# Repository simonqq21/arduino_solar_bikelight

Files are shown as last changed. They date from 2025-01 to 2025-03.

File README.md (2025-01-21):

# Arduino Solar Rear Bicycle Light 
## Main Hardware Components
- Arduino Nano
- 6V 1W solar panel 
- TP4056 li-ion charger with BMS chip 
- 18650 battery holder with 18650 battery x1  
- 10k resistor (charging input voltage divider)
- 50k resistor (charging input voltage divider) 
- 10k resistor (battery voltage divider)
- 50k resistor (battery panel voltage divider) 
- Diffused red LED x5 (dim light, one as a charging indicator when turned off)
- 150R resistor x5
- Clear red LED x4 (bright light) 
- 150R resistor x4
- 2N3904 NPN transistor x2
- 10k resistor x2
- Momentary pushbutton 

## Things to calculate/ measure: 
solar panel no-load voltage 
solar panel max current
expected battery charge time 
expected runtime 
voltage divider resistances 

assume 6V max voltage input, 5V max voltage output 
6 * r2 / (r1 + r2) = 5 
6 * r2 = 5 * (r1 + r2)
6 * r2 = 5 * r1 + 5 * r2 
r2 = 5 * r1 
The current through the voltage divider must be minimal. 
if r2 is 50k, r1 is 10k.

LED current limiting resistors 
diffused LED 

Li-ion voltage max 4.2V 
LED current = 20mA
(4.2-2.1)/0.02 = 105 R resistor minimum

clear LED

Li-ion voltage max 4.2V 
LED current = 30mA
(4.2-2.1)/0.03 = 70 R resistor minimum

Calculations for the voltage divider resistances when using the internal 1.1V Vref 

Min input (PV panel and USB charger) voltage: 0V
Max input (PV panel and USB charger) voltage: 7V
max USB charger voltage: 5V
max PV panel voltage: ~7V - 0.3V = 6.7V (0.3V voltage drop from the diode)
Max input (PV panel and USB charger) voltage: 6.7 ~= 7V
Vin = 7V 
Vout = 1.1V
7* r2/(r1+r2) = 1.1
7r2 = 1.1r1 + 1.1r2 
5.9r2 = 1.1r1 
r1 = 5.9r2/1.1
r2 = 10k 
r1 = 53636.364 ~= 53k 

Min battery voltage: 3.0V
Max battery voltage: 4.2V
Vin = 4.2V
Vout = 1.1V
4.2* r2/(r1+r2) = 1.1 
4.2r2 = 1.1r1 + 1.1r2 
3.1r2 = 1.1r1
r1 = 3.1r2 / 1.1 
r2 = 10k  
r1 = 28181.818 ~= 28k 

Battery voltage divider 
r1 = 50k 
r2 = 10k 
input voltage min: 3.0V
input voltage max: 4.2V
conversion factor = 10k/(50k+10k) = 1/6 
3.0V*1/6 = 0.5V 
4.2V*1/6 = 0.7V
0.5/1.1*1023=465 
0.7/1.1*1023=651

Charging input voltage divider 
r1 = 50k 
r2 = 10k 
input voltage min: 0.0V
input voltage max: 7.0V
input voltage threshold: 4.8V 
conversion factor = 10k/(50k+10k) = 1/6 
0.0V*1/6 = 0V 
7.0V*1/6 = 1.167V
4.8V*1/6 = 0.8V  
1.167/1.1*1023=1023 (capped at 1023, but it doesn't matter anyways)
0.8/1.1*1023=744

# Power Consumption 
power consumption in Off Mode (quiescent current) 35uA
power consumption in Low Mode 78mA
power consumption in High Mode 118mA

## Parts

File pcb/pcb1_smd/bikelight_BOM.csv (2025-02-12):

Designator | Comment | Footprint | LCSC
R6,R7,R8,R9,R10,R11,R12,R13 | 150 | Resistor_SMD:R_0805_2012Metric_Pad1.20x1.40mm_HandSolder | C17471
R2,R3,R4,R5 | 10k | Resistor_SMD:R_0805_2012Metric_Pad1.20x1.40mm_HandSolder | C17414
R1 | 50k | Resistor_SMD:R_0805_2012Metric_Pad1.20x1.40mm_HandSolder | C17737
A1 | Arduino_Nano_v3.x | Module:Arduino_Nano
Q1,Q2,Q3 | BSS138 | Package_TO_SOT_SMD:SOT-23 | C78284
J1 | Conn_01x02 | Connector_JST:JST_XH_B2B-XH-AM_1x02_P2.50mm_Vertical
J2 | Conn_01x05_Pin | Connector_PinHeader_2.54mm:PinHeader_1x05_P2.54mm_Vertical
D1,D2,D3,D4,D5,D6,D7,D8 | LED | LED_THT:LED_D5.0mm
SW1 | SW_Push | Button_Switch_THT:SW_SPST_Omron_B3F-40xx

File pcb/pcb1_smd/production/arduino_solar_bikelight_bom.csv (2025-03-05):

Reference | Value | Footprint | LCSC
R6,R7,R8,R9,R10,R11,R12,R13 | 150 | Resistor_SMD:R_0805_2012Metric_Pad1.20x1.40mm_HandSolder | C17471
R2,R3,R4,R5,R15 | 10k | Resistor_SMD:R_0805_2012Metric_Pad1.20x1.40mm_HandSolder | C17414
R1 | 50k | Resistor_SMD:R_0805_2012Metric_Pad1.20x1.40mm_HandSolder | C17737
A1 | Arduino_Nano_v3.x | Module:Arduino_Nano
Q1,Q2,Q3 | BSS138 | Package_TO_SOT_SMD:SOT-23 | C78284
J1 | Conn_01x02 | Connector_JST:JST_XH_B2B-XH-AM_1x02_P2.50mm_Vertical
J2 | Conn_01x05_Pin | Connector_PinHeader_2.54mm:PinHeader_1x05_P2.54mm_Vertical
R14 | LDR07 | OptoDevice:R_LDR_5.1x4.3mm_P3.4mm_Vertical
D1,D2,D3,D4,D5,D6,D7,D8 | LED | LED_THT:LED_D5.0mm
SW1 | SW_Push | Button_Switch_THT:SW_SPST_Omron_B3F-40xx

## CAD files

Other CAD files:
battery_box v22.f3d

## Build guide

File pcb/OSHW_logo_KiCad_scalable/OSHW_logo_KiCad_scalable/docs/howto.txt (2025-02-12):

How to make your own:
---------------------

Watch / read this first:

* http://www.kicad-pcb.org/display/KICAD/Videos+by+zupnikal

The last two videos should be helpful for how to create a custom .emp file from images.

* http://www.re-innovation.co.uk/web12/index.php/en/blog-75/230-adding-logo-to-kicad

If you use linux (which you should), you don't have to use the online-scaler. Just use the scripts!

---

* Create a folder to hold your new footprint library.
* Copy the scripts 'make_lib.sh' and 'scale.pl' into that folder.
* Make sure these files are executable (chmod u+x ...).
* Copy your custom .emp file into that foler.

* Run the 'make_lib.sh' script as follows:

./make_lib.sh input-file.emp lib-name.mod START END

START and END are placeholders for positive integer numbers (1,2,3...) that determine
the range of created footprint sizes. The units are metric (mm).

The 'lib-name.mod' file will show up in the 'lib' sub-folder. Add it to your pcbnew
library settings as usual.

Footprints that are created for back-layers are automagically mirrored horizontally.
To place them onto a back-layer, hover the mouse-pointer over them and press 'f' for 'flip'.

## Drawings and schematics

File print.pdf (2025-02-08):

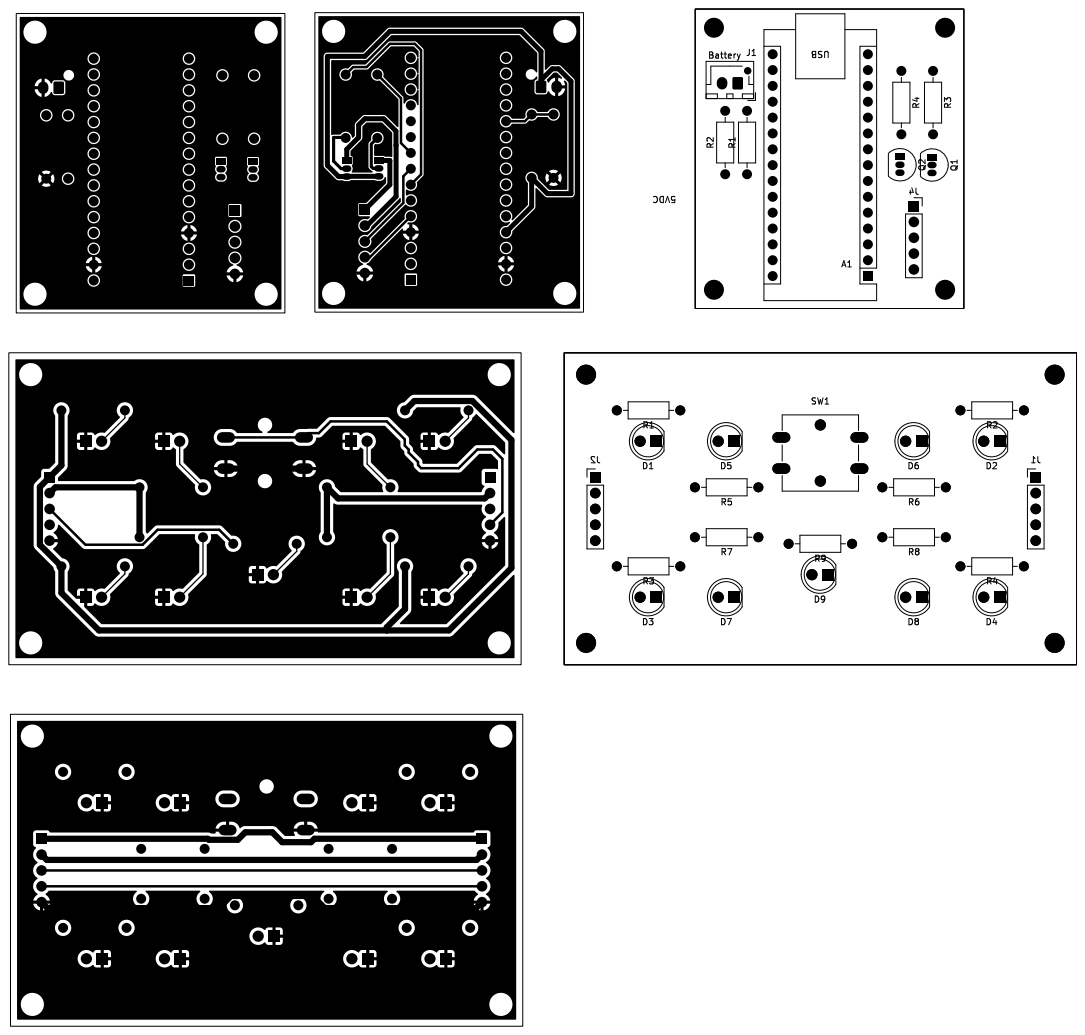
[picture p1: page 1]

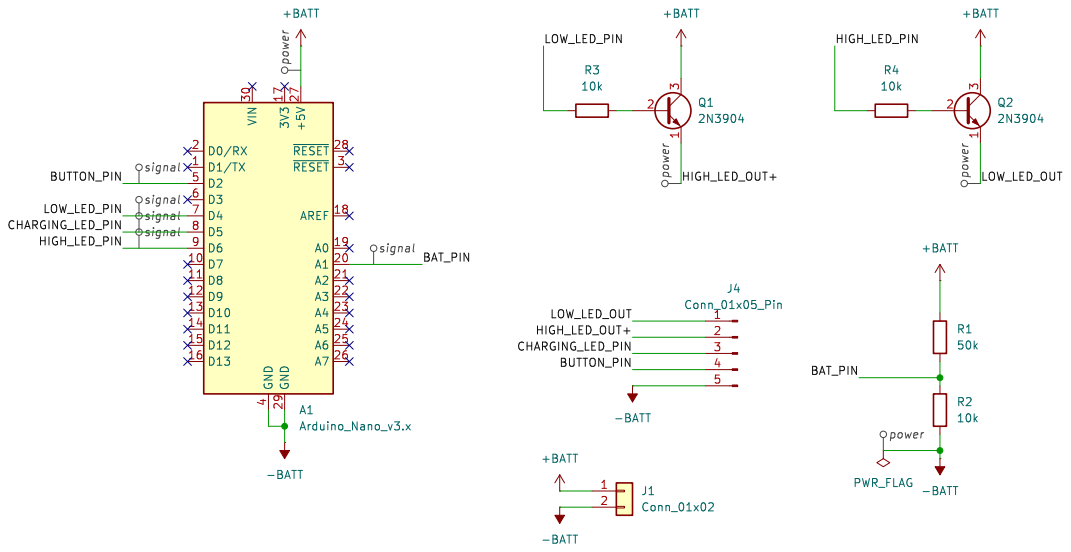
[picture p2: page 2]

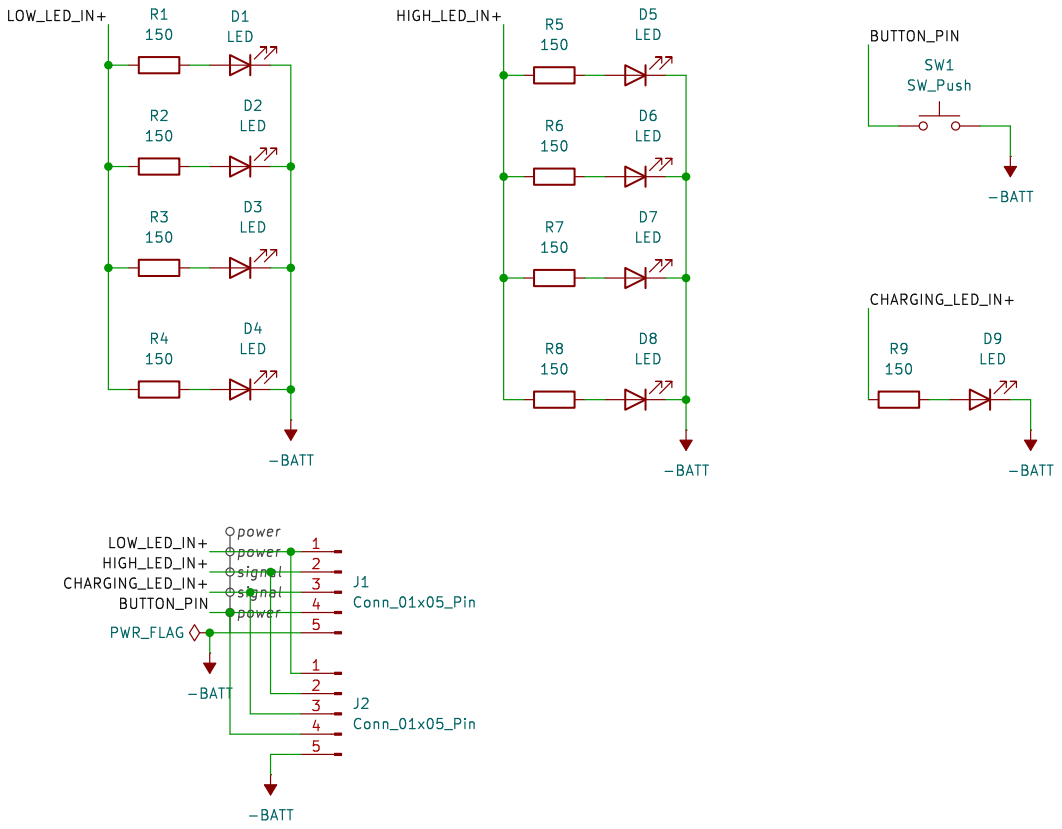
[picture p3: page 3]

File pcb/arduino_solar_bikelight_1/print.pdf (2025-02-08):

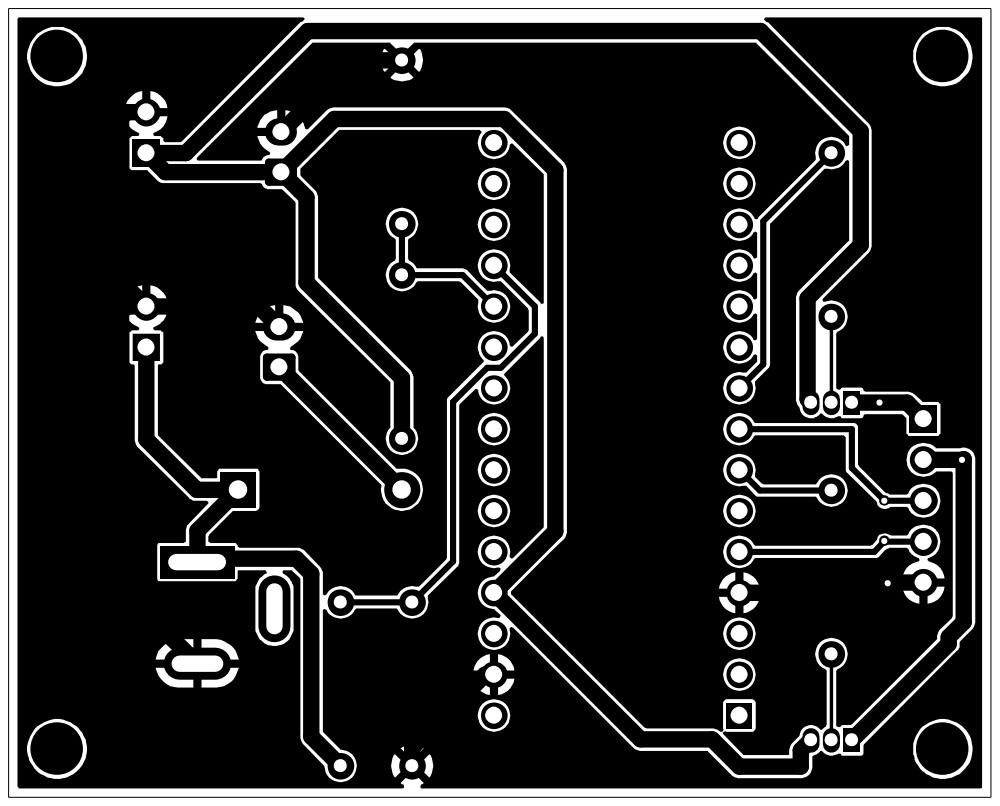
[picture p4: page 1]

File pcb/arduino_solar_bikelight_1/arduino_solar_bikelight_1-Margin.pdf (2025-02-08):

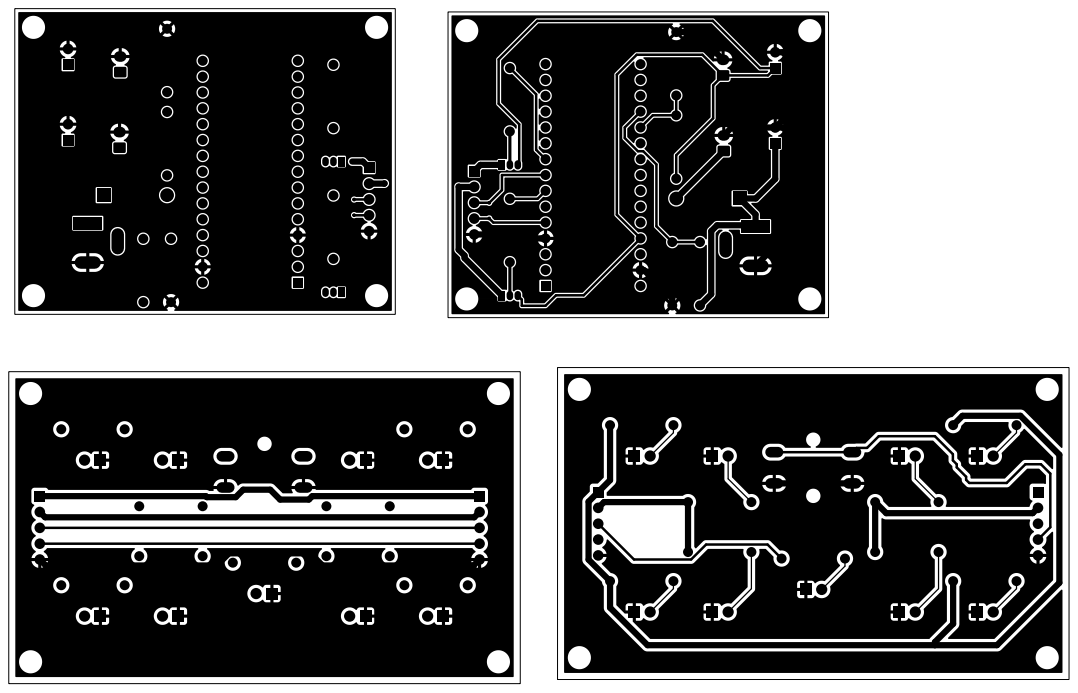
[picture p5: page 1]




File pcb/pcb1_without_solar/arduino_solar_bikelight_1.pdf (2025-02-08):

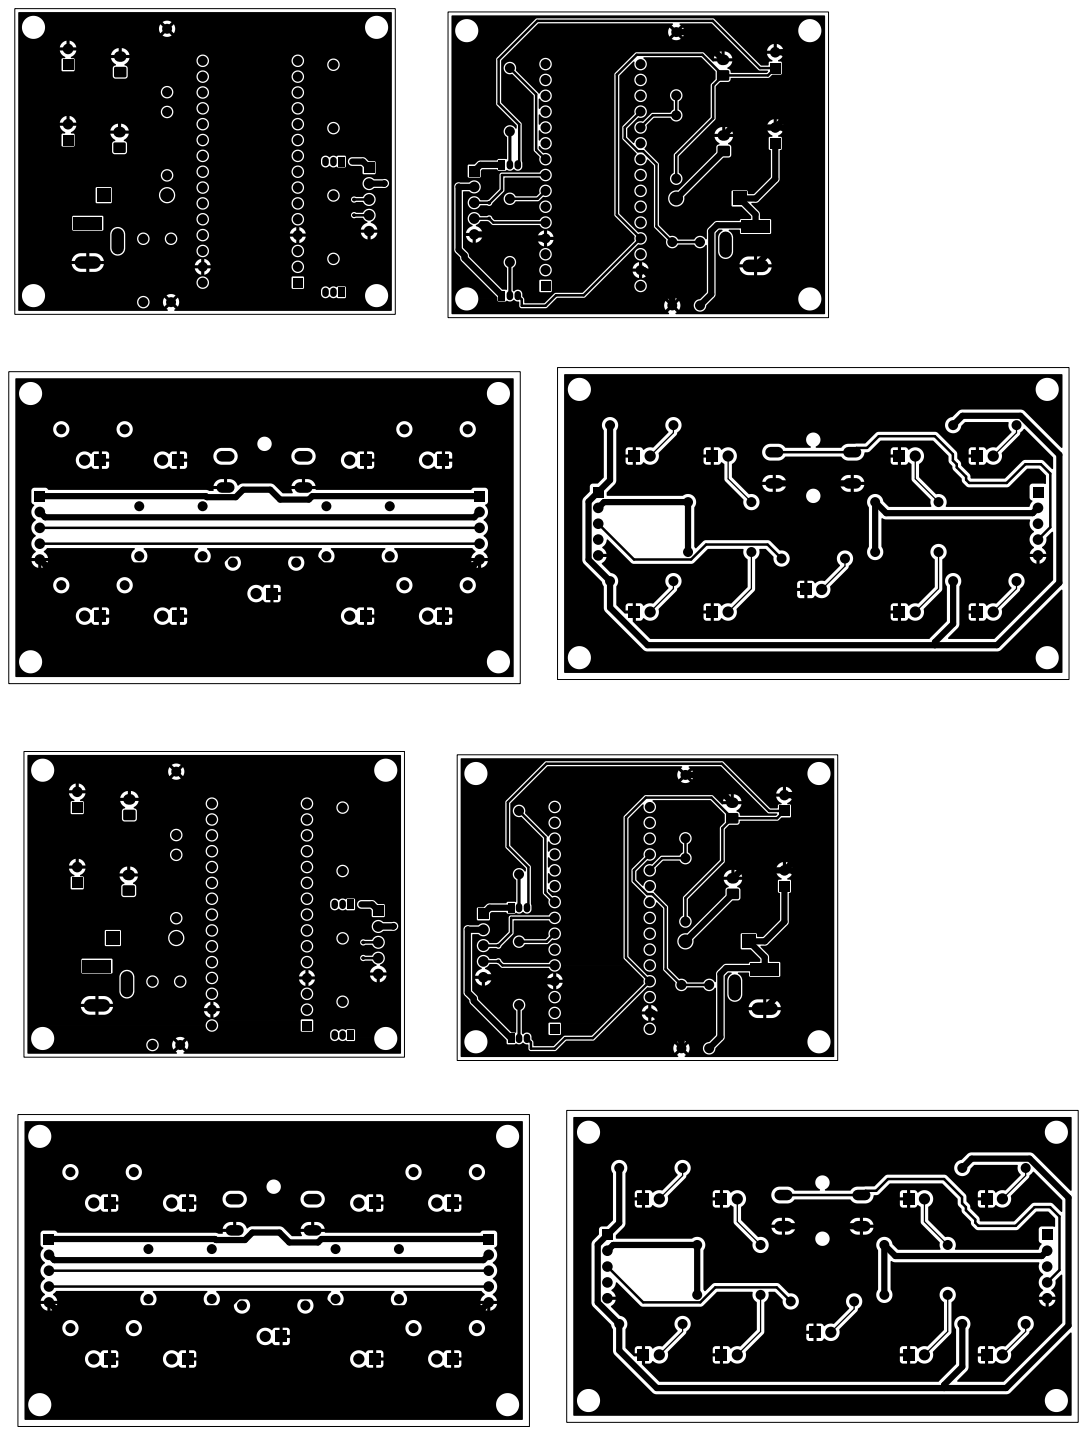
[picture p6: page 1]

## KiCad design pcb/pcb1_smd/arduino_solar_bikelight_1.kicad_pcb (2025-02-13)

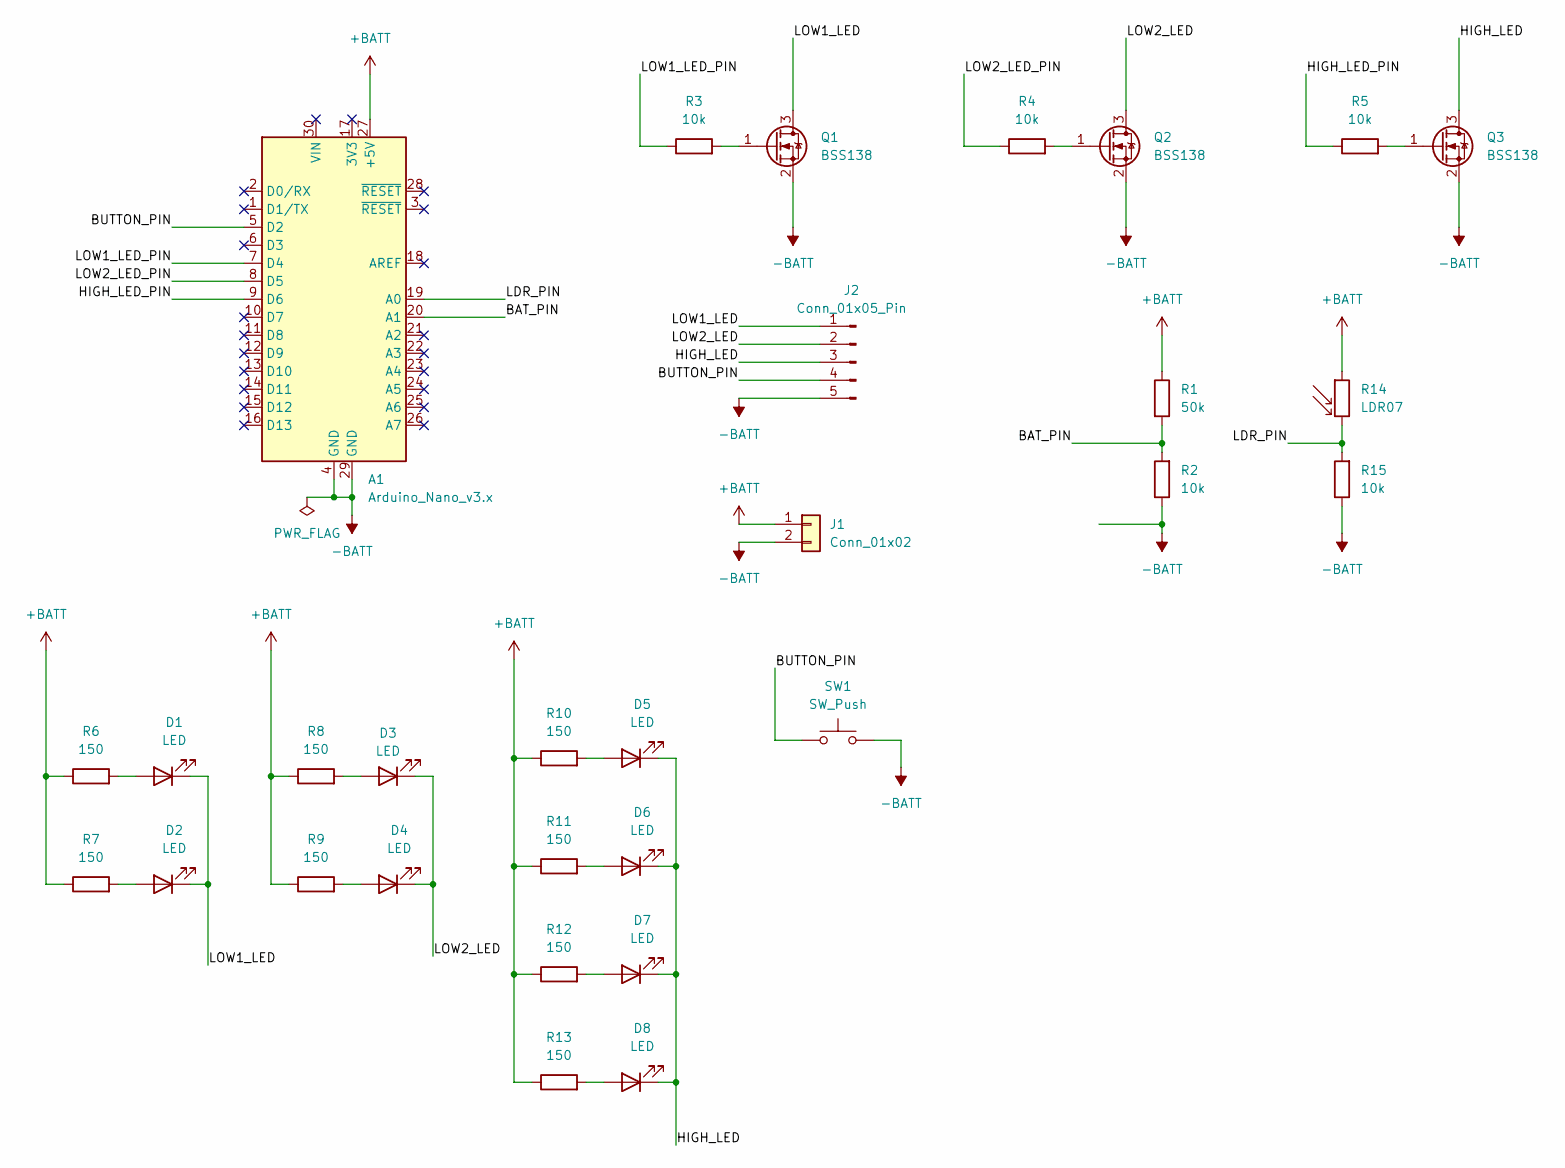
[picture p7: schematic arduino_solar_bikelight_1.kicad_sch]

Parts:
A1: Arduino_Nano_v3.x; Arduino_Nano
D1, D2, D3, D4, D5, D6, D7, D8: LED; LED_D5.0mm
J1: Conn_01x02; JST_XH_B2B-XH-AM_1x02_P2.50mm_Vertical
J2: Conn_01x05_Pin; PinHeader_1x05_P2.54mm_Vertical
Q1, Q2, Q3: BSS138; SOT-23; LCSC C78284
R1: 50k; R_0805_2012Metric_Pad1.20x1.40mm_HandSolder; LCSC C17737
R2, R3, R4, R5, R15: 10k; R_0805_2012Metric_Pad1.20x1.40mm_HandSolder; LCSC C17414
R6, R7, R8, R9, R10, R11, R12, R13: 150; R_0805_2012Metric_Pad1.20x1.40mm_HandSolder; LCSC C17471
R14: LDR07; R_LDR_5.1x4.3mm_P3.4mm_Vertical
SW1: SW_Push; SW_SPST_Omron_B3F-40xx

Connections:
+BATT: A1.27 (+5V), J1.1, R1.1, R6.1, R7.1, R8.1, R9.1, R10.1, R11.1, R12.1, R13.1, R14.1
-BATT: A1.4 (GND), A1.29 (GND), J1.2, J2.5, Q1.2 (S), Q2.2 (S), Q3.2 (S), R2.1, R15.1, SW1.2
/BAT_PIN: A1.20 (A1), R1.2, R2.2
/BUTTON_PIN: A1.5 (D2), J2.4, SW1.1
/HIGH_LED: D5.1 (K), D6.1 (K), D7.1 (K), D8.1 (K), J2.3, Q3.3 (D)
/HIGH_LED_PIN: A1.9 (D6), R5.1
/LDR_PIN: A1.19 (A0), R14.2, R15.2
/LOW1_LED: D1.1 (K), D2.1 (K), J2.1, Q1.3 (D)
/LOW1_LED_PIN: A1.7 (D4), R3.1
/LOW2_LED: D3.1 (K), D4.1 (K), J2.2, Q2.3 (D)
/LOW2_LED_PIN: A1.8 (D5), R4.1
unnamed: D1.2 (A), R6.2
unnamed: D2.2 (A), R7.2
unnamed: D3.2 (A), R8.2
unnamed: D4.2 (A), R9.2
unnamed: D5.2 (A), R10.2
unnamed: D6.2 (A), R11.2
unnamed: D7.2 (A), R12.2
unnamed: D8.2 (A), R13.2
unnamed: Q1.1 (G), R3.2
unnamed: Q2.1 (G), R4.2
unnamed: Q3.1 (G), R5.2

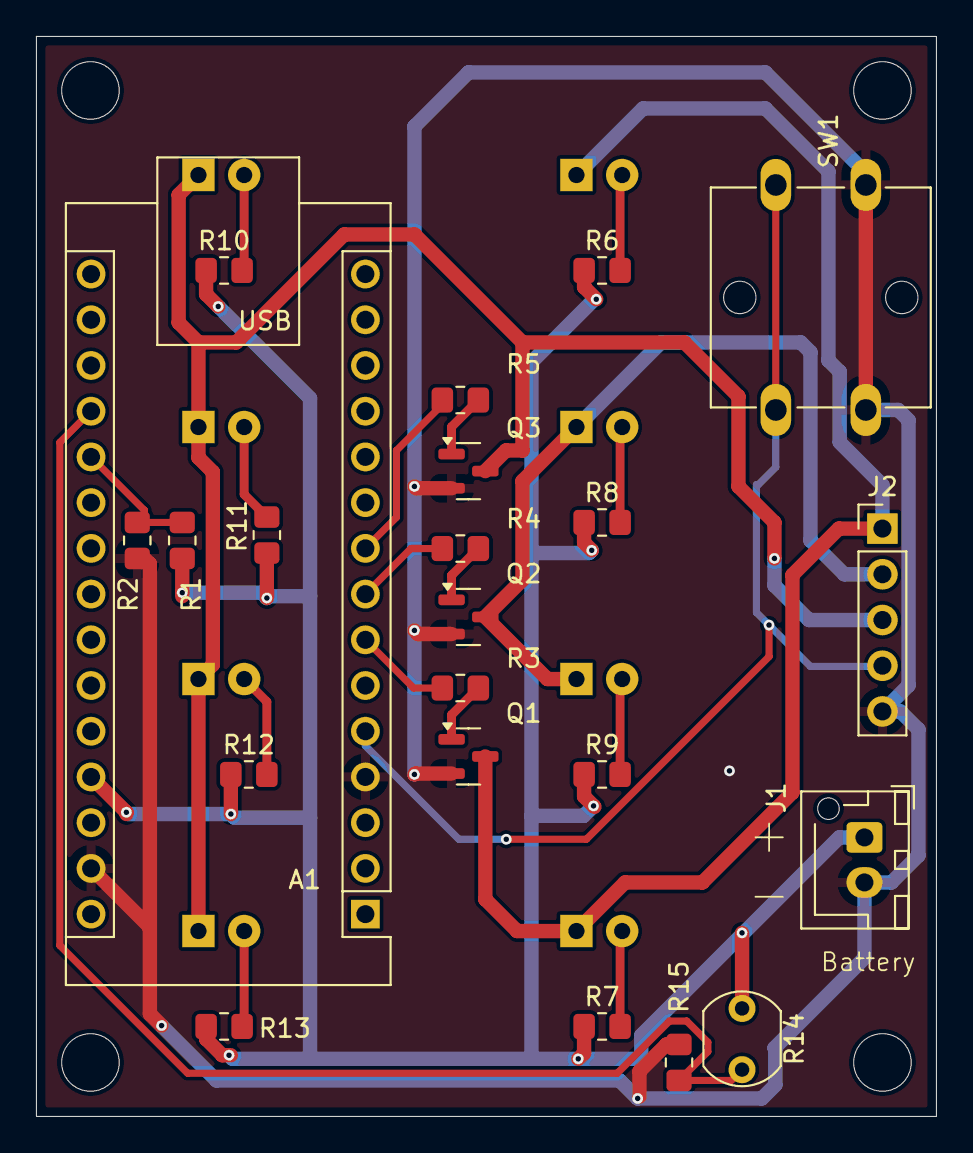
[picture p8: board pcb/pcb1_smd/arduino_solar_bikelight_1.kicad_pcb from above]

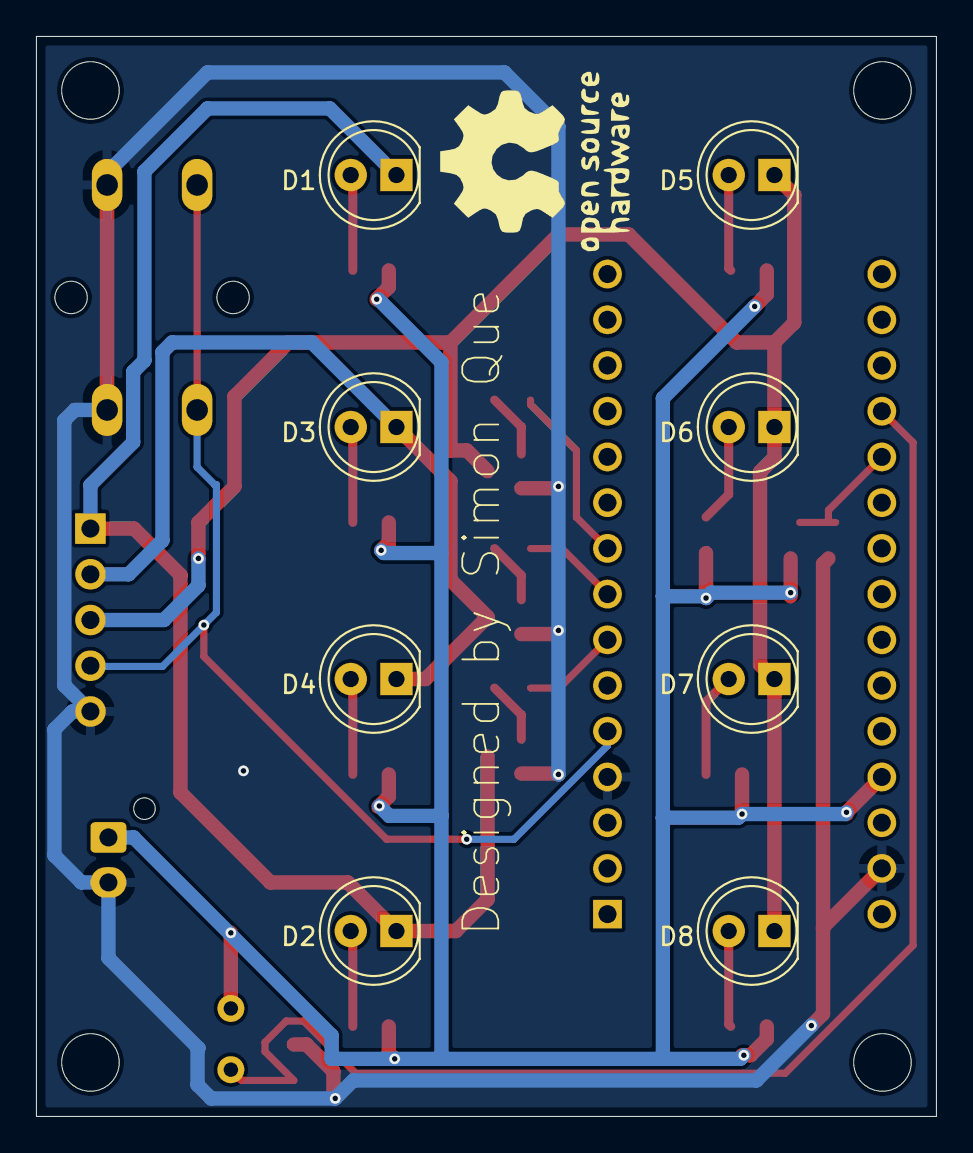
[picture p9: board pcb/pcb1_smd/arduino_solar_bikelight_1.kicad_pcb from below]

Board: 2 copper layers, 50.0 x 60.0 mm, 30 parts (8 on the bottom side), 22 nets.

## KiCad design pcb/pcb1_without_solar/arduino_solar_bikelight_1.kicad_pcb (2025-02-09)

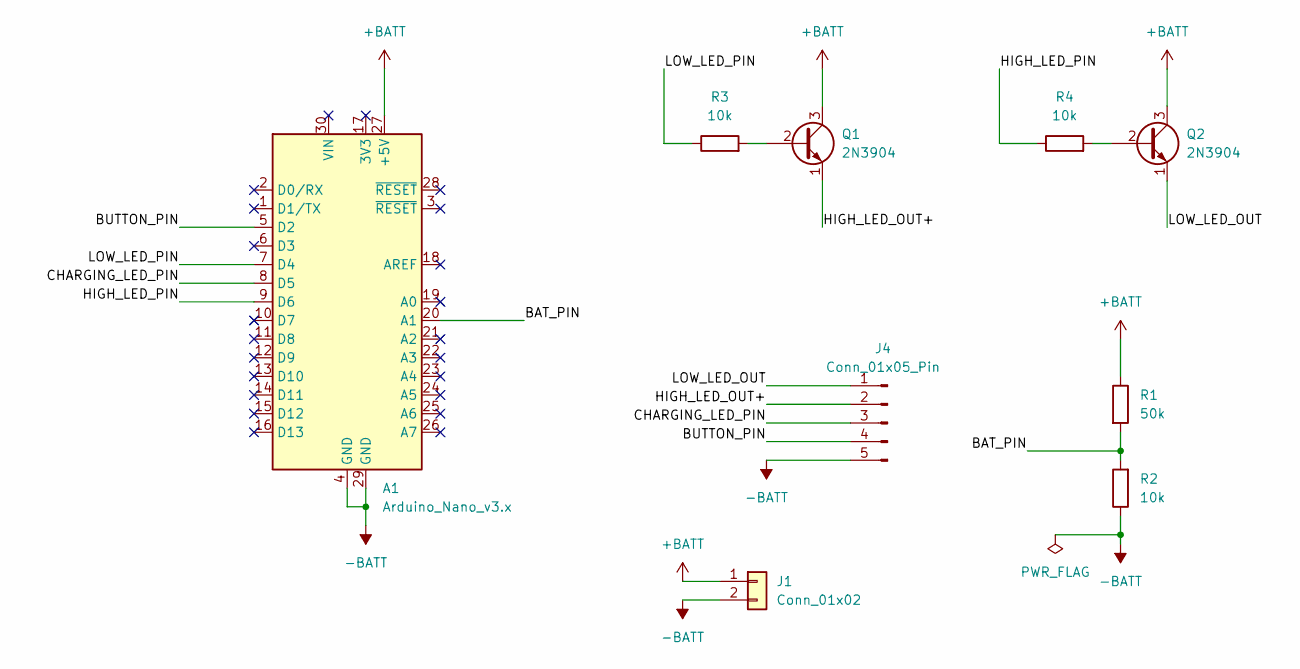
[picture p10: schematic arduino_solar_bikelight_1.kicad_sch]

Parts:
A1: Arduino_Nano_v3.x; Arduino_Nano
J1: Conn_01x02; JST_XH_B2B-XH-AM_1x02_P2.50mm_Vertical
J4: Conn_01x05_Pin; PinHeader_1x05_P2.54mm_Vertical
Q1, Q2: 2N3904; TO-92_Inline
R1: 50k; R_Axial_DIN0207_L6.3mm_D2.5mm_P10.16mm_Horizontal
R2, R3, R4: 10k; R_Axial_DIN0207_L6.3mm_D2.5mm_P10.16mm_Horizontal

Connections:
+BATT: A1.27 (+5V), J1.1, Q1.3 (C), Q2.3 (C), R1.1
-BATT: A1.4 (GND), A1.29 (GND), J1.2, J4.5, R2.1
/BAT_PIN: A1.20 (A1), R1.2, R2.2
/BUTTON_PIN: A1.5 (D2), J4.4
/CHARGING_LED_PIN: A1.8 (D5), J4.3
/HIGH_LED_OUT+: J4.2, Q1.1 (E)
/HIGH_LED_PIN: A1.9 (D6), R4.1
/LOW_LED_OUT: J4.1, Q2.1 (E)
/LOW_LED_PIN: A1.7 (D4), R3.1
unnamed: Q1.2 (B), R3.2
unnamed: Q2.2 (B), R4.2

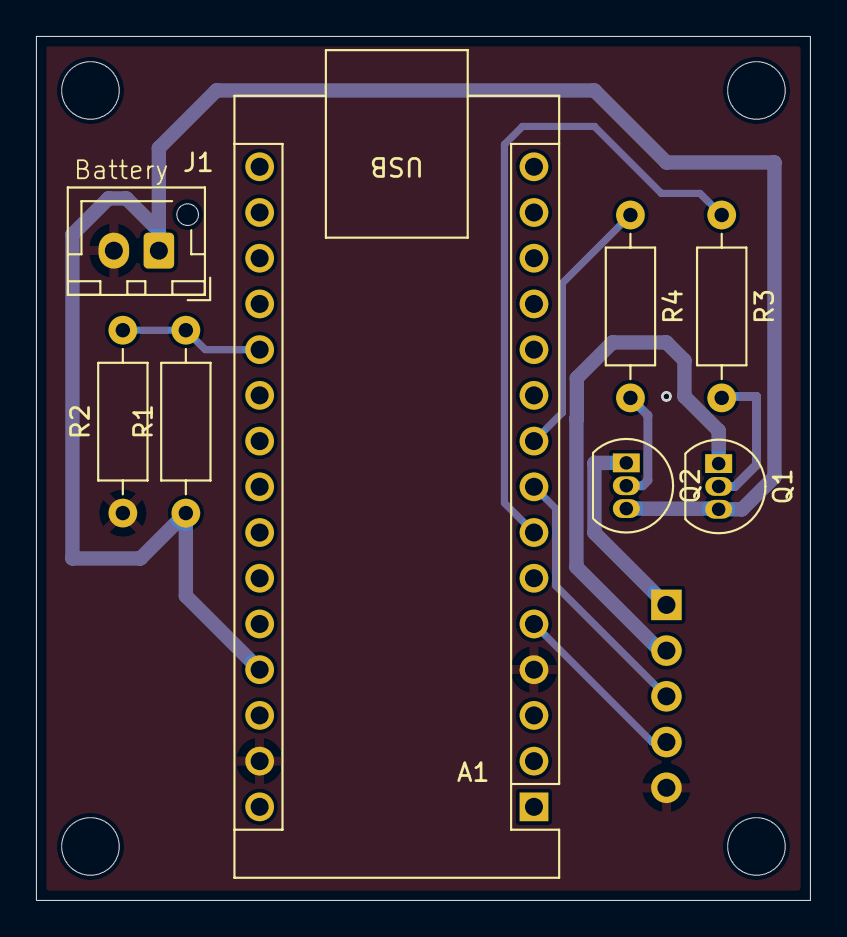
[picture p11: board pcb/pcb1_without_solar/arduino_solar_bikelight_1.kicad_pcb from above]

Board: 2 copper layers, 43.0 x 48.0 mm, 9 parts (1 on the bottom side), 11 nets.

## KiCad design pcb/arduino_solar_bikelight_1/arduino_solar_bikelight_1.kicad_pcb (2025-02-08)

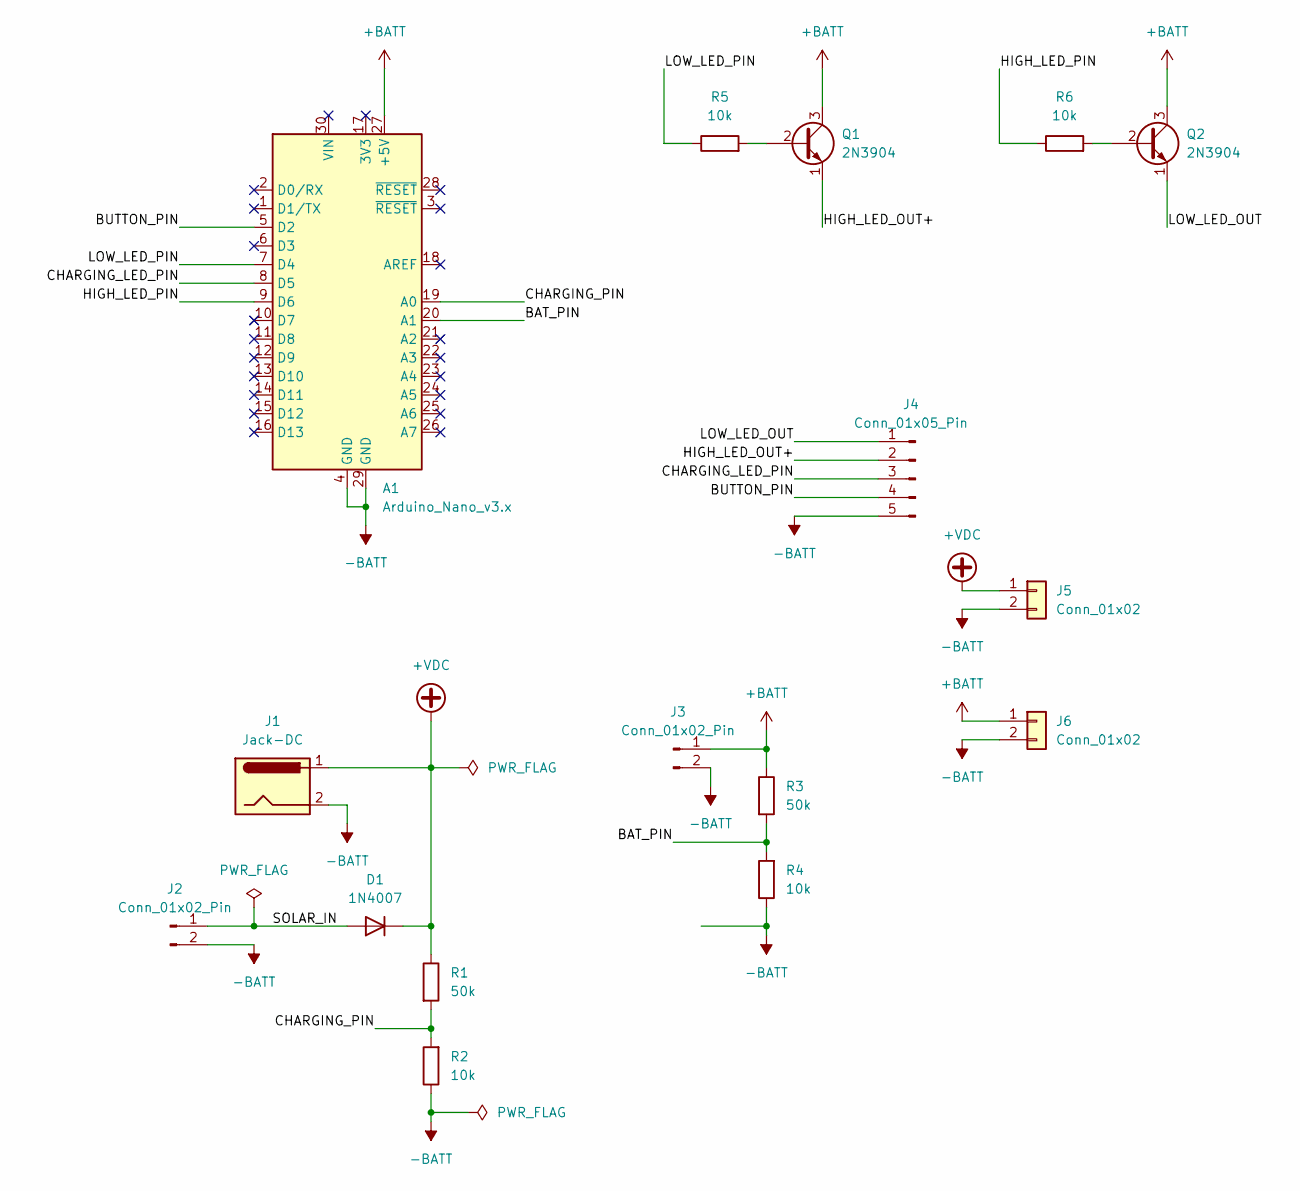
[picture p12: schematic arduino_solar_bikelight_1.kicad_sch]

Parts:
A1: Arduino_Nano_v3.x; Arduino_Nano
D1: 1N4007; D_DO-41_SOD81_P10.16mm_Horizontal
J1: Jack-DC; BarrelJack_GCT_DCJ200-10-A_Horizontal
J2, J3: Conn_01x02_Pin; JST_XH_B2B-XH-A_1x02_P2.50mm_Vertical
J4: Conn_01x05_Pin; PinHeader_1x05_P2.54mm_Vertical
J5, J6: Conn_01x02; PinHeader_2x01_P2.54mm_Vertical
Q1, Q2: 2N3904; TO-92_Inline
R1, R3: 50k; R_Axial_DIN0207_L6.3mm_D2.5mm_P10.16mm_Horizontal
R2, R4, R5, R6: 10k; R_Axial_DIN0207_L6.3mm_D2.5mm_P10.16mm_Horizontal

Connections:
+BATT: A1.27 (+5V), J3.1, J6.1, Q1.3 (C), Q2.3 (C), R3.1
+VDC: D1.1 (K), J1.1, J5.1, R1.1
-BATT: A1.4 (GND), A1.29 (GND), J1.2, J2.2, J3.2, J4.5, J5.2, J6.2, R2.1, R4.1
/BAT_PIN: A1.20 (A1), R3.2, R4.2
/BUTTON_PIN: A1.5 (D2), J4.4
/CHARGING_LED_PIN: A1.8 (D5), J4.3
/CHARGING_PIN: A1.19 (A0), R1.2, R2.2
/HIGH_LED_OUT+: J4.2, Q1.1 (E)
/HIGH_LED_PIN: A1.9 (D6), R6.1
/LOW_LED_OUT: J4.1, Q2.1 (E)
/LOW_LED_PIN: A1.7 (D4), R5.1
/SOLAR_IN: D1.2 (A), J2.1
unnamed: Q1.2 (B), R5.2
unnamed: Q2.2 (B), R6.2

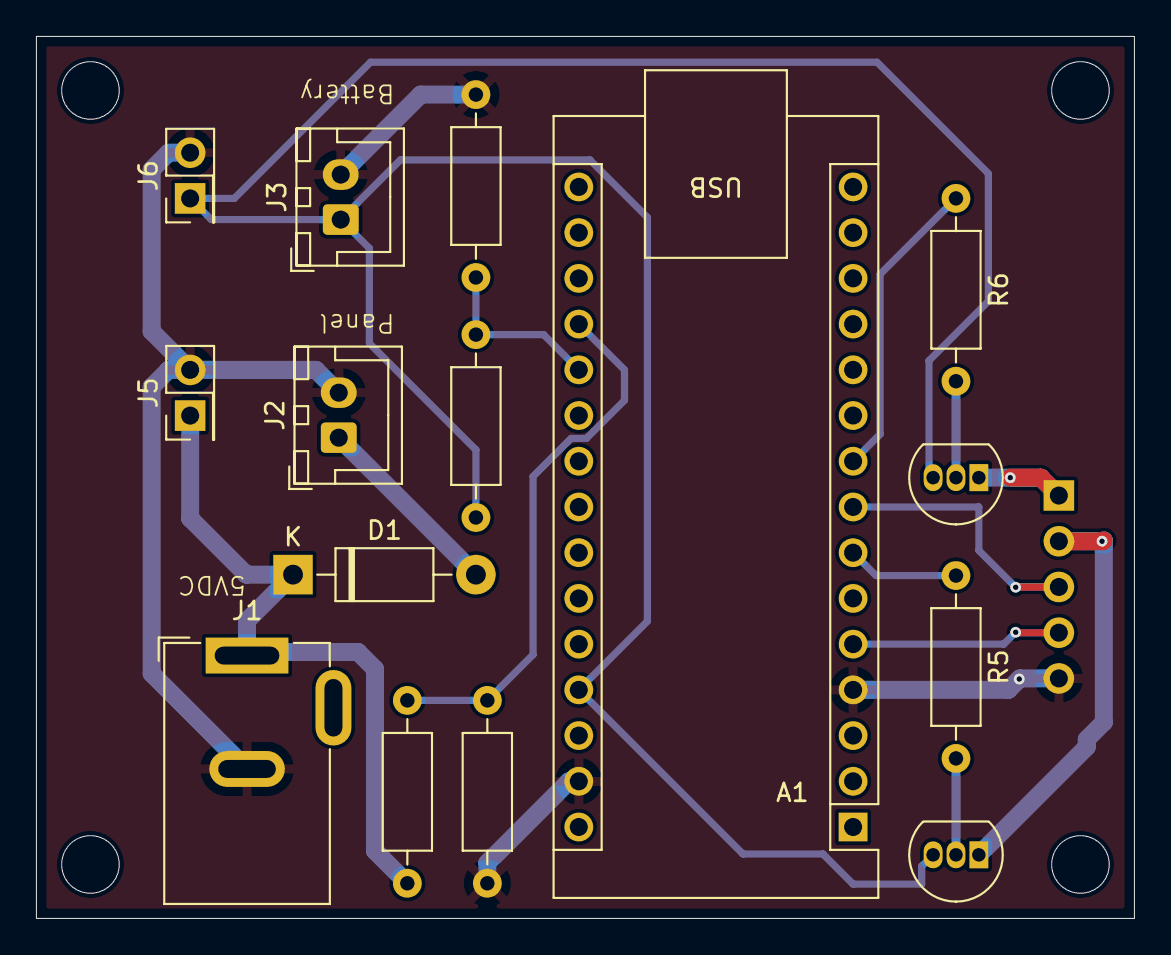
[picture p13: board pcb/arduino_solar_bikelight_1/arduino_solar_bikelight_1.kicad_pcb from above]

Board: 2 copper layers, 61.0 x 49.0 mm, 16 parts (1 on the bottom side), 14 nets.

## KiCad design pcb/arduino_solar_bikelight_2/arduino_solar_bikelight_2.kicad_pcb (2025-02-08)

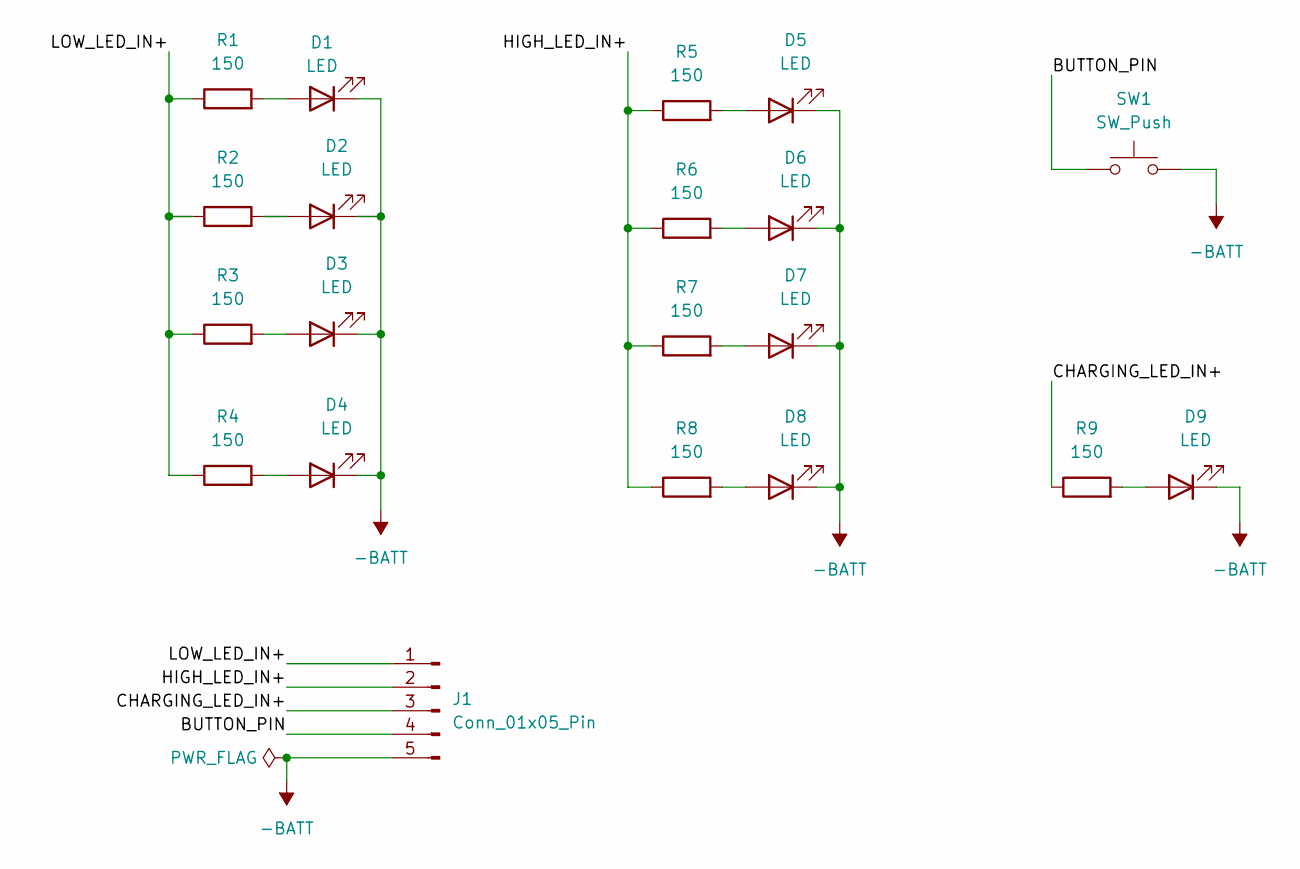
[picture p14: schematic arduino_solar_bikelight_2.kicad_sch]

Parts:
D1, D2, D3, D4, D5, D6, D7, D8, D9: LED; LED_D5.0mm
J1: Conn_01x05_Pin; PinSocket_1x05_P2.54mm_Vertical
R1, R2, R3, R4, R5, R6, R7, R8, R9: 150; R_Axial_DIN0207_L6.3mm_D2.5mm_P10.16mm_Horizontal
SW1: SW_Push; SW_SPST_Omron_B3F-40xx

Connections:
-BATT: D1.1 (K), D2.1 (K), D3.1 (K), D4.1 (K), D5.1 (K), D6.1 (K), D7.1 (K), D8.1 (K), D9.1 (K), J1.5, SW1.2; also elsewhere on the board
/BUTTON_PIN: J1.4, SW1.1; also elsewhere on the board
/CHARGING_LED_IN+: J1.3, R9.1; also elsewhere on the board
/HIGH_LED_IN+: J1.2, R5.1, R6.1, R7.1, R8.1; also elsewhere on the board
/LOW_LED_IN+: J1.1, R1.1, R2.1, R3.1, R4.1; also elsewhere on the board
unnamed: D1.2 (A), R1.2
unnamed: D2.2 (A), R2.2
unnamed: D3.2 (A), R3.2
unnamed: D4.2 (A), R4.2
unnamed: D5.2 (A), R5.2
unnamed: D6.2 (A), R6.2
unnamed: D7.2 (A), R7.2
unnamed: D8.2 (A), R8.2
unnamed: D9.2 (A), R9.2

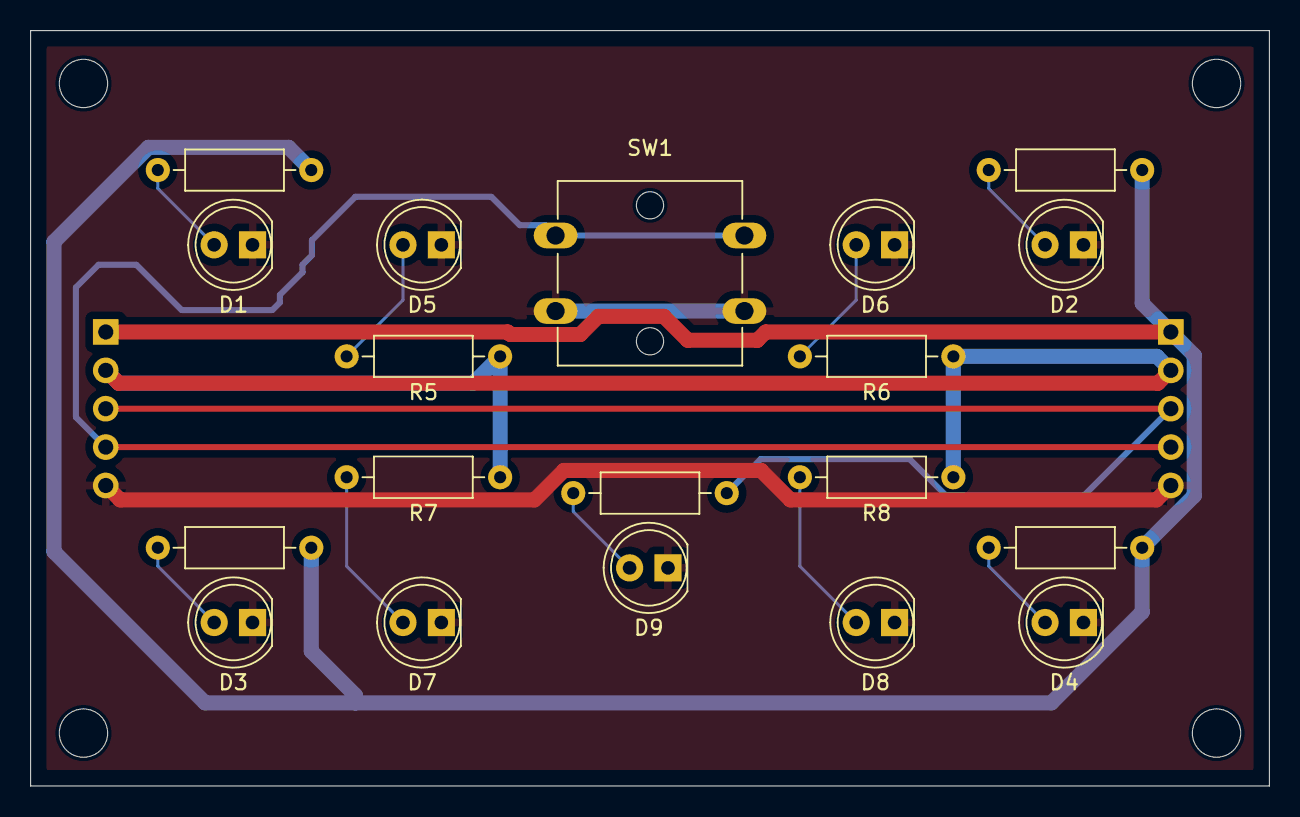
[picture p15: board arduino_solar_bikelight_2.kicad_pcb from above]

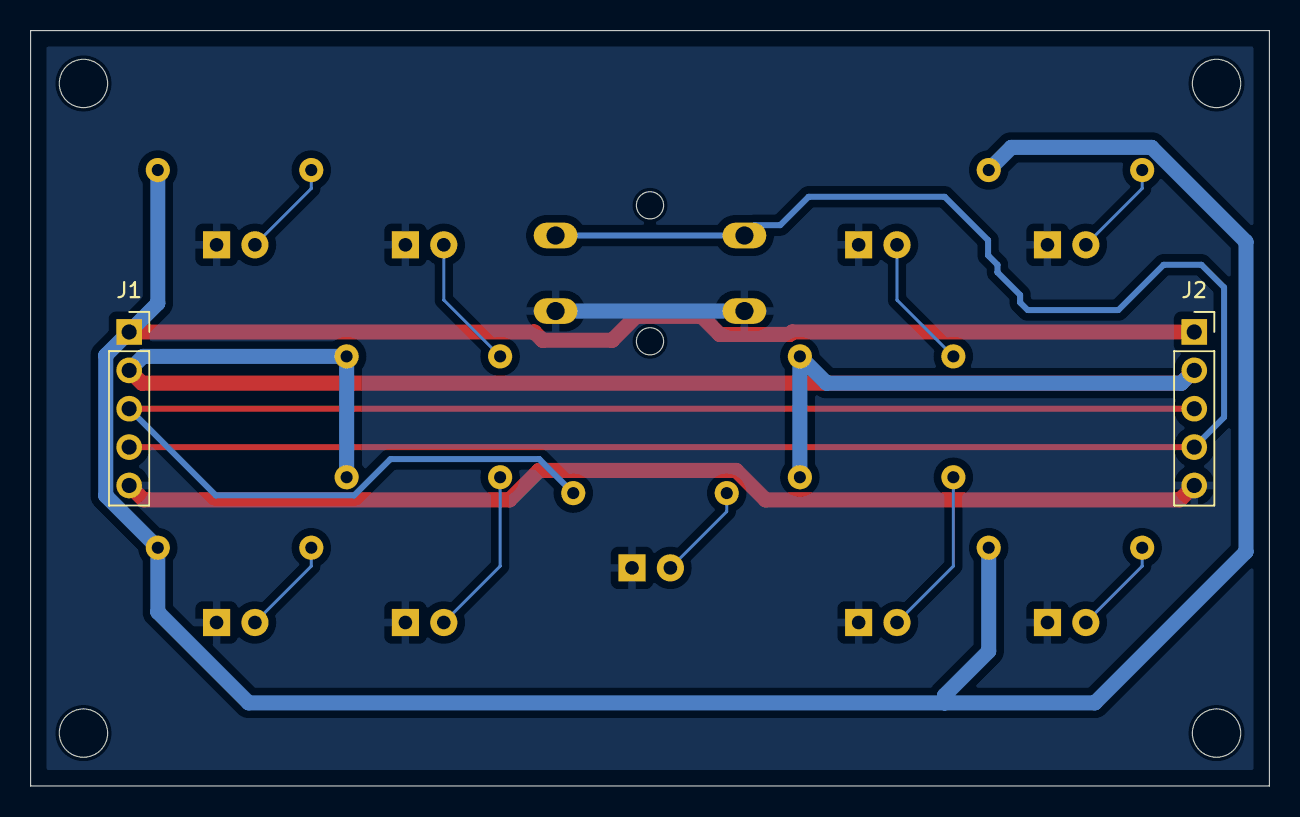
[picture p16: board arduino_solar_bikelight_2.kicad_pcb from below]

Board: 2 copper layers, 82.0 x 50.0 mm, 21 parts (2 on the bottom side), 14 nets.

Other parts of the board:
J2: Conn_01x05_Pin; PinSocket_1x05_P2.54mm_Vertical

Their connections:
-BATT: J2.5; also elsewhere on the board
/BUTTON_PIN: J2.4; also elsewhere on the board
/CHARGING_LED_IN+: J2.3; also elsewhere on the board
/HIGH_LED_IN+: J2.2; also elsewhere on the board
/LOW_LED_IN+: J2.1; also elsewhere on the board

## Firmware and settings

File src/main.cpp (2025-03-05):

/**
 * TODO: 
 * auto mode
 */
#include <Arduino.h>
#include "math.h"
#include "buttonlib2.h"
#include "LEDlib.h"
#include <avr/sleep.h>  
#include <avr/wdt.h> 
#include <EEPROM.h> 

/**
 * low LEDs - 7 dim red LEDs 
 * high LEDs - 4 bright red LEDs 
 * charging LED - 1 dim red LED (identical to low LEDs, also used for rear light)
 */

const int btn1Pin = 2;
InterruptButton btn1(btn1Pin);
const int lowLEDs2Pin = 4;
const int lowLEDsPin = 5;
const int highLEDsPin = 6;
// const int chargingPin = A0;
const int batPin = A1;
LED lowLEDs(lowLEDsPin);
LED lowLEDs2(lowLEDs2Pin);
LED highLEDs(highLEDsPin);
unsigned int deadBatCountDown, lowBatCountDown; 

/**
 * Modes: 
 * 0 - off - all LEDs off
 * 1 - extended low - low LEDs off, charging LEDs on, high LEDs flashing
 * 2 - low - low LEDs on, charging LEDs on, high LEDs off
 * 3 - high - low LEDs on, charging LEDs on, high LEDs on
 * 4 - flashing - low LEDs on, charging LEDs on, high LEDs flashing
 * 5 - fading - low LEDs on, charging LEDs on, high LEDs fading
 * 6 - charging(either via USB port or solar panel) - low LEDs off, charging LEDs on, high LEDs off
 * charging LED is off when (not charging and off), and on when (the low LEDs are on or when charging)
 */
byte curMode = 0;
byte savedMode;

/** automatic mode  
 * If true, the light will turn off when it is being charged (either via solar or USB) and turn on 
 *  when charging stops. This makes the light turn off in bright light and turn on in the dark.
 * If false, the light will remain turned on regardless if it is being charged or not until the user 
 *  turns it off.
 * */ 
bool autoMode = false; 
int chargingPinReading;
double chargingPinVolts, batVolts;
bool lowBattery, deadBattery;
bool isCharging; 
bool isSleeping; 

// update period for fading modes
unsigned int updatePeriodinMillis = 5;
// period length for flashing and fading modes
const int totalPeriodLengthinMillis = 1000;
// keypoints per mode cycle 
unsigned int keyPoints[4];
// flashCycleTimer - used to keep time
unsigned long flashCycleTimer;
unsigned long powerOnTime; 
unsigned long lastTimeBtnDoubleClicked; 
unsigned long lastTimeBtnClicked;
unsigned long lastTimeChargingVoltsExceeded;
const double chargingThresholdVolts = 4.0;
const double deadBatVolts = 3.2;
const double lowBatVolts = 3.78;
// const double lowBatVolts = 4.8;
const double hysteresisBatVolts = 0.1;

/**
 * ctr1 is a counter variable used to animate the LEDs.
 * ctr1 is measured in multiples of updatePeriodinMillis milliseconds, which varies 
 * depending on the mode. For example, it could be in multiples of 5 ms for fading, or 100 ms
 * for flashing.
 */
unsigned int ctr1;
unsigned long lastTimePrinted = 0;
const bool debug = true;

void startSleepTimer() {
  powerOnTime = millis();
  isSleeping = false;
}

/**
 * single click - switch and cycle through modes
 */
void btn1_1shortclick_func() {
  // restart sleep timer
  startSleepTimer();
  lastTimeBtnClicked = millis();
  // if auto mode is turned on and the light is charging, 
  // set current mode to saved mode.
  if (autoMode && isCharging) {
    curMode = savedMode;
  }
  // if the battery voltage is lower than the defined low battery 
  // voltage plus a certain buffer value, it is considered battery low 
  // when the button is pressed.
  if (batVolts < lowBatVolts + hysteresisBatVolts) {
    lowBattery = true;
  }
  // if the battery is low and the current mode is greater than extended low mode, 
  // set current mode to off mode.
  if ((lowBattery && curMode >= 1) || deadBattery) {
    curMode = 0;
  }
  // else, increment the current mode.
  else {
    curMode++;
  }
  // Cycle current mode to zero when it exceeds the last mode.
  if (curMode > 5) {
    curMode = 0;
  }
  // if auto mode is turned on, 
  // set saved mode to current mode.
  if (autoMode) {
    savedMode = curMode;
  }
  if (debug) {
    Serial.print("curMode = ");
    Serial.println(curMode);
  }
  // reset watchdog timer
  wdt_reset();
}

/**
 * double click - toggle autoMode
 */
void btn1_2shortclick_func() {
  lastTimeBtnDoubleClicked = millis();
  lastTimeBtnClicked = millis();
  startSleepTimer();
  autoMode = !autoMode; 
  lowLEDs2.setLoopUnitDuration(200);
  if (autoMode) {
    bool loopSeq[] = {0,1,0,1,0};
    lowLEDs2.startTimer(1000, true);
    lowLEDs2.setLoopSequence(loopSeq, 5);
    lowLEDs2.startLoop();
  } else {
    bool loopSeq[] = {0,1,0,0,0};
    lowLEDs2.startTimer(1000, true);
    lowLEDs2.setLoopSequence(loopSeq, 5);
    lowLEDs2.startLoop();
  }
  if (debug) {
    Serial.print("autoMode=");
    Serial.println(autoMode);
    Serial.print("mode=");
    Serial.print(curMode);
    Serial.println(); 
  }
  // reset watchdog timer
  wdt_reset();
  
}

// ISR for interrupt button library 
void btn1_change_func() {
  btn1.changeInterruptFunc();
}

// ISR for waking up from deep sleep
void wakeupISR() {
  ADCSRA |= 1 << ADEN;
  startSleepTimer(); 
  btn1_1shortclick_func();
  btn1.begin(btn1_change_func);
  // reset button temporarily to prevent double trigger
  btn1.reset();
}



void checkBatVolts() {
  batVolts = analogRead(batPin)*1.1/1023.0*6;
  // turn off the light if the battery voltage is waaay too low
  if (batVolts <= deadBatVolts) {
    deadBatCountDown++;
    lowBatCountDown = 0;
    if (deadBatCountDown > 10) {
      deadBatCountDown = 0;
      curMode = 0;
      lowBattery = true;
      deadBattery = true;
    }
  } 
  // turn on the light in extended low mode if battery is low and the light is turned on 
  else if (batVolts > deadBatVolts && batVolts <= lowBatVolts) {
    deadBatCountDown = 0;
    lowBatCountDown++;
    if (lowBatCountDown > 10) {
      lowBatCountDown = 0;
      lowBattery = true;
    deadBattery = false;
    }
  } 
  else {
    deadBatCountDown = 0;
    lowBatCountDown = 0;
    lowBattery = false;
    deadBattery = false;
  }
  if (curMode > 1 && lowBattery) {
    curMode = 1;
  }
}

/**

If the light is in autoMode {
  If the light is charging {
    If the saved mode is different from the current mode {
      Save the current mode 
      // Set current mode to zero 
    }
    If the button is pressed {
      Set current mode to the saved mode
      Increment the current mode in a cycle 
      Start a timer lightsTimer that keeps the lights on five seconds 
        before it turns off due to autoMode and charging.
      When that timer exceeds 5 seconds {
        Save the current mode 
        Set current mode to zero
      }
    }
  }
  Else if the light is not charging {
    Resume the saved mode
  }
}
Else if the light is not in autoMode {
  Maintain the current mode 
  If the saved mode is nonzero and the current mode is zero {
    Resume the saved mode
  }
}

*/

void checkAutoMode() {
  if (!deadBattery) {
    if (autoMode) {
      // Serial.print("curMode = ");
      // Serial.print(curMode);
      // Serial.print(", savedmode = ");
      // Serial.print(savedMode);
      // Serial.print(" ischarging=");
      // Serial.print(isCharging);
      // Serial.println();
      if (isCharging) {
        // Serial.print(chargingPinReading);
        // Serial.print(", ");
        // Serial.print(chargingPinVolts);
        // Serial.print(", ");
        // Serial.print(chargingThresholdVolts);
        // Serial.print(", ");
        // Serial.print("ischarging=");
        // Serial.print(isCharging);
        // Serial.println();
        if (millis() - lastTimeBtnClicked > 4000) {
          if (curMode) {
            savedMode = curMode;
            curMode = 0;
          }
        } 
      } 
      else {
        if (curMode != savedMode && savedMode) {
          curMode = savedMode;
          btn1.begin(btn1_change_func);
          // reset button temporarily to prevent double trigger
          btn1.reset();
        }
      }
    }
  }
  else {
    // Serial.print("deadbattery=");
    // Serial.print(deadBattery);
    // Serial.print(", batvolts = ");
    // Serial.print(batVolts);
    // Serial.println();
    savedMode = 0;
  }
}

// ISR triggered by watchdog timer every 1 seconds during deep sleep,
// before going back to sleep.
ISR (WDT_vect) {
  ADCSRA |= 1 << ADEN;
  wdt_reset();
  checkBatVolts(); 
  // updateChargeLED();
  checkAutoMode();
  checkBatVolts();
}

/**
 * mode 0 - Off Mode
 */
void offMode() {
  lowLEDs.off();
  lowLEDs2.off();
  highLEDs.off();
  if (millis() - powerOnTime > 3000) {
    isSleeping = true;
    // set interrupt to perform the watchdog ISR every four seconds then go back to sleep
    // clear MCU Status Register
    MCUSR = 0;
    // set watchdog timer change enable and watchdog enable
    WDTCSR = 1 << WDCE | 1 << WDE;
    // set WDP3 to WDP0 to trigger watchdog interrupt every 4 seconds and 
    // set WDIE enable watchdog interrupt
    // WDTCSR = bit(WDIE) | 1 << WDP3 & ~bit (WDP2) & ~bit (WDP1) & ~bit (WDP0);
    // WDTCSR = 1 << WDIE | 1 << WDP3 | 0 << WDP2 | 0 << WDP1 | 0 << WDP0;
    WDTCSR = 1 << WDIE | 0 << WDP3 | 1 << WDP2 | 1 << WDP1 | 0 << WDP0;

    // sleep CPU until woken up by the button
    set_sleep_mode(SLEEP_MODE_PWR_DOWN);
    sleep_enable();
    detachInterrupt(digitalPinToInterrupt(2));
    attachInterrupt(digitalPinToInterrupt(2), wakeupISR, LOW);  
    // sleep_mode(); 
    // sei();
    ADCSRA = 0;
    // turn off brown-out enable in software
    MCUCR = bit (BODS) | bit (BODSE);  // turn on brown-out enable select
    MCUCR = bit (BODS);        // this must be done within 4 clock cycles of above
    interrupts ();             // guarantees next instruction executed

    sleep_cpu();
    // sleep_disable();
    // sei();
    // detachInterrupt(digitalPinToInterrupt(2));
    // btn1.begin(btn1_change_func);
  }
}

/**
 * mode 1 - Extended Low Mode 
 * dim LEDs flashing, charging LED on, bright LEDs off
 */
void extendedLowMode() {
  highLEDs.off();
  lowLEDs.on();
  // 1 Hz, single 30% DC flash
  updatePeriodinMillis = 100;
  keyPoints[0] = 0;
  keyPoints[1] = keyPoints[0] + 300/updatePeriodinMillis;
  keyPoints[2] = totalPeriodLengthinMillis/updatePeriodinMillis;
  if (millis() - flashCycleTimer >= updatePeriodinMillis) {
    flashCycleTimer = millis();
    if (ctr1 < keyPoints[1]) {
      lowLEDs2.set(true);
    } else lowLEDs2.set(false);
    ctr1 = ctr1 > keyPoints[2] - 1? 0:ctr1 + 1;
  }
}

/**
 * mode 2 - Low Mode 
 * dim LEDs on, charging LED on, bright LEDs off
 */
void lowMode() {
  lowLEDs.on();
  lowLEDs2.on();
  highLEDs.off();
}

/**
 * mode 3 - High Mode 
 * dim LEDs on, charging LED on, bright LEDs on
 */
void highMode() {
  lowLEDs.on();
  highLEDs.on();
}

/**
 * mode 4 - Flashing Mode 
 * dim LEDs on, charging LED on, bright LEDs flashing
 */
void flashingMode() {
  // 1 Hz, single 30% DC flash
  updatePeriodinMillis = 100;
  keyPoints[0] = 0;
  keyPoints[1] = keyPoints[0] + 300/updatePeriodinMillis;
  keyPoints[2] = totalPeriodLengthinMillis/updatePeriodinMillis;
  lowLEDs.on();
  if (millis() - flashCycleTimer >= updatePeriodinMillis) {
    flashCycleTimer = millis();
    if (ctr1 < keyPoints[1]) {
      highLEDs.set(true);
    } 
    else highLEDs.set(false);
    ctr1 = ctr1 > keyPoints[2] - 1? 0:ctr1 + 1;
  }
}

/**
 * mode 5 - Fading Mode 
 * dim LEDs on, charging LED on, bright LEDs fading
 */
void fadingMode() {
  lowLEDs.on();
  updatePeriodinMillis = 5;
  keyPoints[0] = 0;
  keyPoints[1] = keyPoints[0] + 400/updatePeriodinMillis;
  keyPoints[2] = keyPoints[1] + 400/updatePeriodinMillis;
  keyPoints[3] = keyPoints[2] + 200/updatePeriodinMillis;
  // 1 Hz fade; 400 mS rise, 400 mS fall, 200 mS off
  // 5 ms fading steps
  // 200 total steps; 0,80,160,200
  if (millis() - flashCycleTimer >= updatePeriodinMillis) {
    flashCycleTimer = millis();
    if (ctr1 < keyPoints[1]) {
      highLEDs.aSet(sin(0.5 * PI * (ctr1-keyPoints[0]) / (keyPoints[1] - keyPoints[0]))*255);
    } 
    else if (ctr1 >= keyPoints[1] && ctr1 < keyPoints[2]) {
      highLEDs.aSet(sin(PI * (0.5 + 0.5 * (ctr1-keyPoints[1]) / (keyPoints[2] - keyPoints[1]))) * 255);
    } 
    else if (ctr1 >= keyPoints[2]) {
      highLEDs.aSet(0);
    }
    ctr1 = ctr1 > keyPoints[3] - 1? 0:ctr1 + 1;
  }
}

void setup() {
  wdt_reset();
  wdt_disable();
  if (debug) Serial.begin(115200);
  Serial.println("start");
  btn1.begin(btn1_change_func);
  btn1.set1ShortPressFunc(btn1_1shortclick_func);
  btn1.set2ShortPressFunc(btn1_2shortclick_func);
  lowLEDs.begin();
  lowLEDs2.begin();
  highLEDs.begin();
  analogReference(INTERNAL);
}

void loop() {
  btn1.loop();
  lowLEDs.loop();
  lowLEDs2.loop();
  highLEDs.loop();
  
  switch (curMode) {
    case 1:
      extendedLowMode();
      break;
    case 2:
      lowMode();
      break;
    case 3:
      highMode();
      break;
    case 4:
      flashingMode();
      break;
    case 5:
      fadingMode();
      break;
    default: 
      offMode();
  }
  checkBatVolts(); 
  // updateChargeLED();
  checkAutoMode();
  checkBatVolts(); 
  
  if (debug) {
    if (millis() - lastTimePrinted > 10) {
      lastTimePrinted = millis();
      // Serial.print(analogRead(chargingPin));
      // Serial.print(", ");
      // Serial.print(analogRead(batPin));
      // Serial.print(chargingPinVolts);
      // Serial.print(", ");
      // Serial.print(batVolts);
      // Serial.print("ischarging=");
      // Serial.print(isCharging);
      // Serial.print("mode=");
      // Serial.print(curMode);
      // Serial.println(); 
    }
  }
  
}


// #include <avr/sleep.h>
// #include <avr/power.h>
// #include <Arduino.h> 

// void setup () 
// {
//   set_sleep_mode (SLEEP_MODE_PWR_DOWN);  
//   noInterrupts ();           // timed sequence follows
//   sleep_enable();
 
//   ADCSRA = 0;
//   // turn off brown-out enable in software
//   MCUCR = bit (BODS) | bit (BODSE);  // turn on brown-out enable select
//   MCUCR = bit (BODS);        // this must be done within 4 clock cycles of above
//   interrupts ();             // guarantees next instruction executed
//   sleep_cpu ();              // sleep within 3 clock cycles of above
// }  // end of setup

// void loop () { }


/**
 * When the bike light is in Off Mode, 
 *  if the battery is charging, turn on the charging LED, 
 *  else turn off the charging LED. 
 */
// void updateChargeLED() {
//   if (!isSleeping && millis() - lastTimeBtnDoubleClicked < 1000) {
//     return;
//   }
//   chargingPinReading = analogRead(chargingPin);
//   chargingPinVolts = chargingPinReading*1.1/1023.0*6;
//   if (chargingPinVolts > chargingThresholdVolts || curMode > 0) { 
//     chargingLEDs.on();
//   } else {
//     chargingLEDs.off();
//   }
//   // charging pin value debouncing
//   // 
//   if (chargingPinVolts <= chargingThresholdVolts) {
//     lastTimeChargingVoltsExceeded = millis();
//   }
//   if (millis() - lastTimeChargingVoltsExceeded > 500 && chargingPinVolts > chargingThresholdVolts) {
//     isCharging = true;
//   }
//   else {
//     isCharging = false;
//   }
//   // Serial.print(chargingPinVolts);
//   // Serial.print(", ");
//   // Serial.print(chargingThresholdVolts);
//   // Serial.print(", ");
  
// }

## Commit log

2025-01-12 working arduino code, but needs power consumption optimization and code cleanup
2025-01-15 working sleep mode but charging LED isn't working when sleeping
2025-01-15 working sleep mode and watchdog timer with charging LED working in deepsleep
2025-01-15 fixed bug where clicking button when off sends it directly to mode 2 because of button bouncing
2025-01-16 comments set WDT interrupt to 4s
2025-01-16 initial calculations for initial BOM, testing measurements to follow
2025-01-20 pio upload using Arduino as ISP
2025-01-21 calculations for voltage dividers using 1v1 Vref
2025-01-21 two voltage dividers: 1 for charging and another for battery low voltage cutoff improved charging indicator LED behavior added an extended low mode
2025-01-21 fixed bug with low battery mode not turning off when button is pressed
    [main.cpp]
2025-01-22 working low battery mode
2025-01-22 working doubleclick function to toggle autoMode working led indication for autoMode TODO: change light behavior based on autoMode save autoMode to EEPROM
2025-01-23 fixed bug with charging LED not working when sleeping
    [main.cpp]
2025-01-23 put button shortclick function in button wakeup ISR instead of hardcoding curMode=1
    [main.cpp]
2025-01-24 fixed bug with automatic drop down to extended low mode on low battery detection
    [main.cpp]
2025-01-24 added hysteresis to low battery detection at button press to smooth out the voltage spikes caused by the LEDs switching
2025-01-24 added averaging code for ADC so that a sudden dip or spike won't create a false low battery or dead battery event Improved the stability of the system added dead battery condition to checkAutoMode to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
    [main.cpp]
2025-01-24 fixed bug where the mode is set to zero when battery is low but not dead.
    [main.cpp]
2025-01-24 added some code to disable ADC while sleeping
2025-01-26 started work on PCB
    [arduino_solar_bikelight_1.kicad_pcb, arduino_solar_bikelight_1.kicad_sch]
2025-01-27 placed components in schematic and assigned footprints
    [arduino_solar_bikelight_1.kicad_sch, arduino_solar_bikelight_2.kicad_pcb, arduino_solar_bikelight_2.kicad_sch]
2025-01-29 completed PCB1 currently working on PCB2
    [arduino_solar_bikelight_1.kicad_pcb, arduino_solar_bikelight_1.kicad_sch, arduino_solar_bikelight_2.kicad_pcb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]
2025-02-08 updated schematic and pcb to have a non solar, non charging version for simplicity exported svg, gerber, and pdf files
    [arduino_solar_bikelight_1-B_Cu.gbr, arduino_solar_bikelight_1-B_Mask.gbr, arduino_solar_bikelight_1-B_Paste.gbr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]
2025-02-10 added smd version with mosfets in place of bjts
    [arduino_solar_bikelight_1.kicad_pcb, arduino_solar_bikelight_1.kicad_sch, arduino_solar_bikelight_2.kicad_pcb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]
2025-02-10 completed the latest updated design of the PCB with SMT parts and MOSFETs
    [arduino_solar_bikelight_1.kicad_pcb]
2025-02-12 learned how to export BOM and CPL and gerbers added graphics and text at the back silkscreen
    [arduino_solar_bikelight_1-B_Cu.gbl, arduino_solar_bikelight_1-B_Mask.gbs, arduino_solar_bikelight_1-B_Paste.gbp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]
2025-02-13 added LDR to board and exported to production
    [arduino_solar_bikelight_1-B_Cu.gbl, arduino_solar_bikelight_1-B_Mask.gbs, arduino_solar_bikelight_1-B_Paste.gbp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]
2025-03-05 battery box 3d model
    [arduino_solar_bikelight_bom.csv, battery_box v22.f3d]
